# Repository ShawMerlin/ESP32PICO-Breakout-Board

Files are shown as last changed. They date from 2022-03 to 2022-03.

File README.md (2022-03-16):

# ESP32PICO-Breakout-Board

Here I have a simple breakout board for the new ESP32-PICO Chip.
All the parts I have included with JLCPCB Numbers so their assembly service can be used as well.

*Still getting some values on a few decoupling capacitors*

Pre-made Breakout boards for this are $30+ on sites so I wanted a cost effective option for testing this chip.
Feel free to take the Kicad files and change them however you see fit.  Enjoy!!

We want to update our ShawLED Controller board with this little chip, very exciting times!!
www.shawtechlighting.com

Features
* Full USB Integration
* A few breakout GPIO Pins (6)
* RX & TX USB Transfer LEDs
* Switch for hold in boot & reset
* 2 Antenna options (On Board and SMA)
* Switch for changing between the 2 Antenna's



3D Model of a Quarter was put in the picture to give an idea of how tiny this little guy is.  :)


I run a Facebook page for all my electronic/modding adventures.  I post things on there before they end up here on Github.
I love the feedback and comments that people share.  It helps us achieve bigger and better things!!

www.facebook.com/geekislandgaming

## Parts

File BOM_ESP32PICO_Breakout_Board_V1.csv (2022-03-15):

Comment | Designator | Footprint | LCSC | Type
SMA Board Edge Bend | AE2 | ANT-TH_KH-SMA-K513-G | C411575 | E
Boot Button - SKRKAEE020 | SW1,SW2 | SW-SMD-2_2.9x3.9x1.7 | C115357 | E
ANT_Sel | SW3 | SMD | C431540 | E
Diode | D1 | SOD-323 | C124187 | E
Power LED Blue | D2 | LED_0603 | C72041 | B
Orange LED | D3 | LED_0603
Green LED | D4 | LED_0603
10k | R1,R5 | 0603_Resistor | C25804 | B
0R | R2,R6 | 0603_Resistor | C21189 | B
47K | R3 | 0603_Resistor | C25819 | B
470R | R4 | 0603_Resistor | C23179 | B
1.2K Resistor | R7,R8,R9 | 0603_Resistor | C22765 | B
BCM857BS | Q1 | SOT65P210X110-6N | C105887 | E
UMH3N | Q2 | SMD:SOT-363 | C62892 | E
AO3401A | Q3 | SOT95P240X115-3N | C15127 | B
AMS1117 | U1 | SMD:SOT-223-3_TabPin2 | C6186 | B
CP2102 | U2 | QFN-28-1EP_5x5mm_P0.5mm_EP3.35x3.35mm | C6568 | B
TYPE-C-31-M-12 | USB1 | TYPE-C-31_L8.94_W7.3 | C165948 | E
 | C1
 | C3
 | C5
 | C6
.1uF | C2,C9 | 0603_Capacitor | C14663 | B
10uF | C4,C7,C8 | 0603_Capacitor | C96446 | B
ESP32-PICO-D4 | IC2 | QFN-48_EP_7.0x7.0x0.5P | C193707 | E
FerriteBead | FB1 | R_1206_3216Metric | C1002 | B

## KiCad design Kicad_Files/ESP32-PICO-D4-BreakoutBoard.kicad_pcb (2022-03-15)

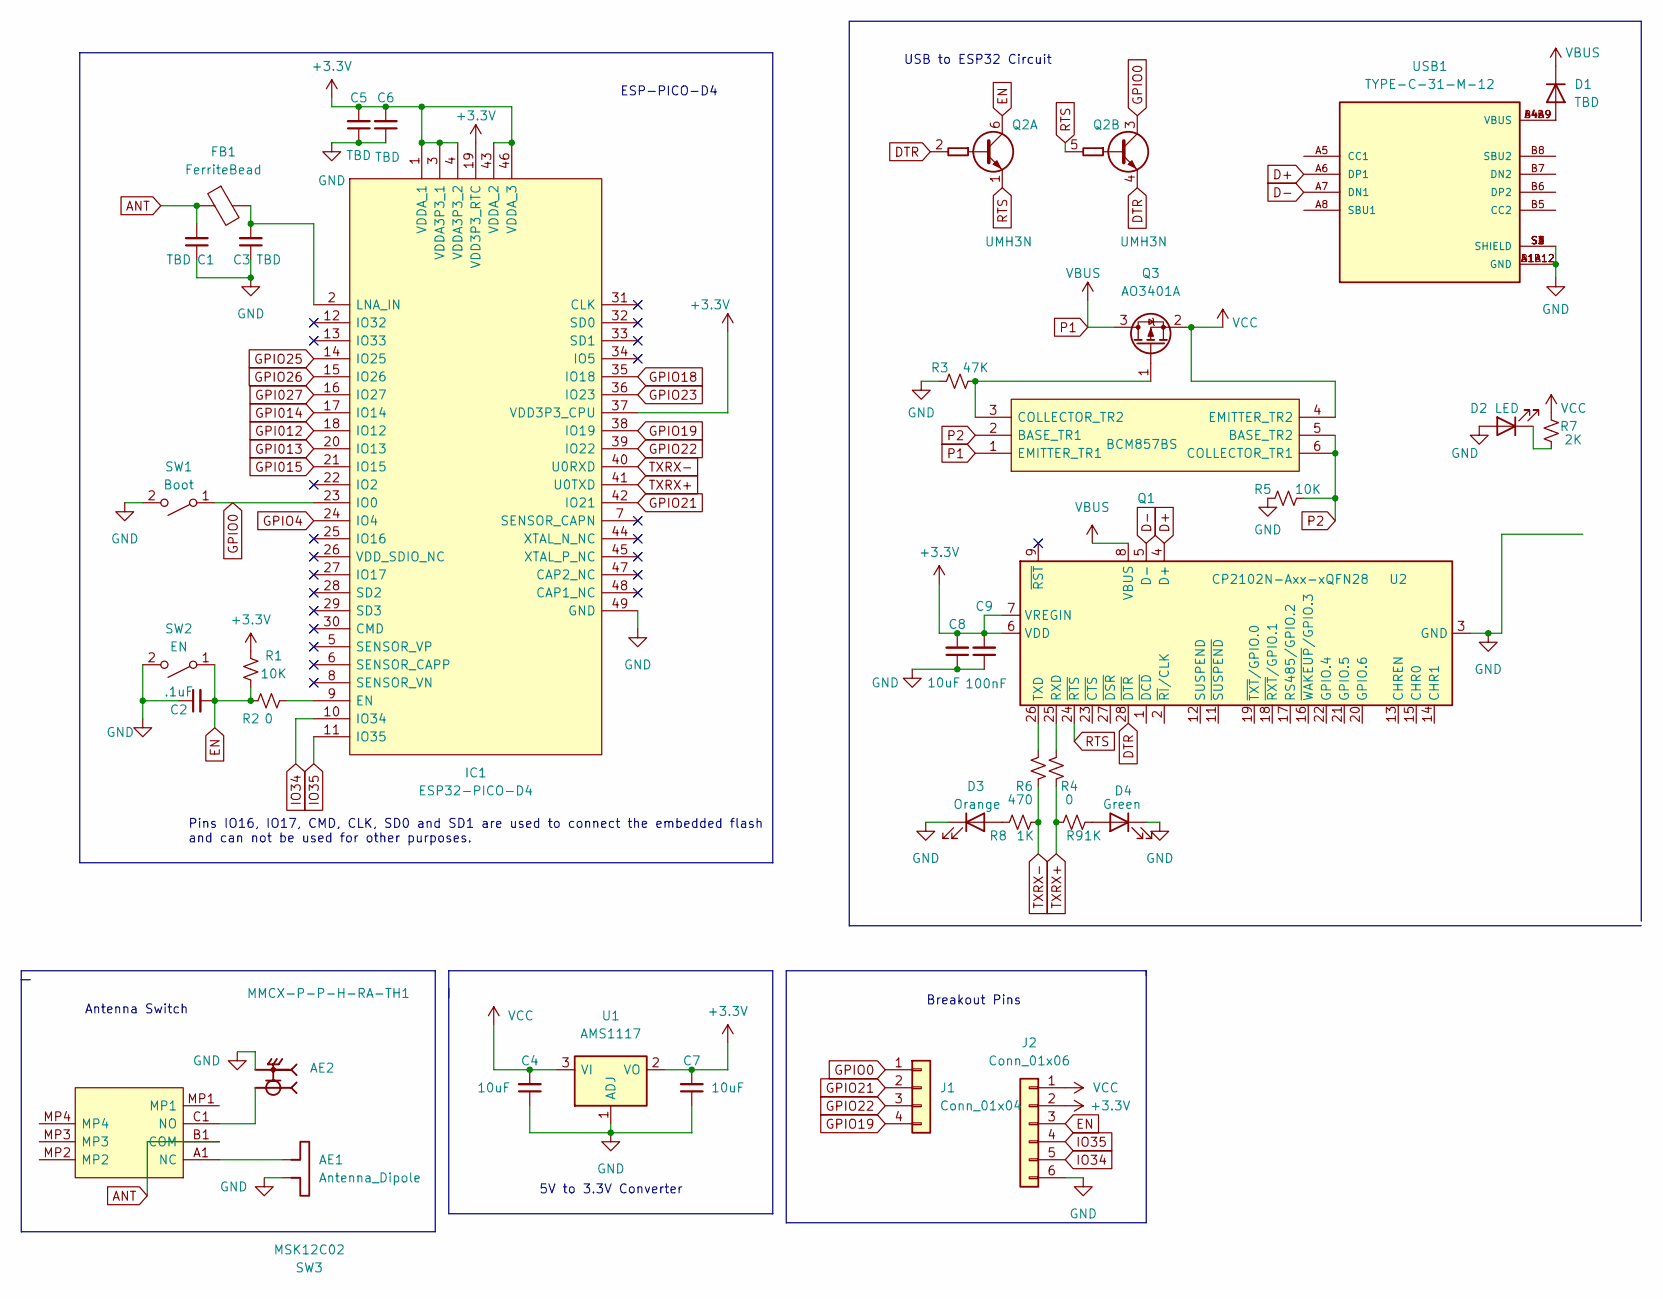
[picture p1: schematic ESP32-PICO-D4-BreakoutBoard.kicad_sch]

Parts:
AE1: Antenna_Dipole; Texas_SWRA117D_2.4GHz_Right
AE2: MMCX-P-P-H-RA-TH1; SAMTEC_MMCX-P-P-H-RA-TH1; PARTREV E
C1, C3, C5, C6: TBD; C_0603_1608Metric
C2: .1uF; C_0603_1608Metric
C4, C7, C8: 10uF; C_0603_1608Metric
C9: 100nF; C_0603_1608Metric
D1: TBD; DIODE_SOD2513X120N
D2: LED; LED_0603_1608Metric
D3: Orange; LED_0603_1608Metric
D4: Green; LED_0603_1608Metric
FB1: FerriteBead; R_1206_3216Metric
IC1: ESP32-PICO-D4; ESP32-PICO-D4-PQFN50P700X700X104-49N; Manufacturer_Part_Number ESP32-PICO-D4; Mouser Part Number 356-ESP32-PICO-D4
J1: Conn_01x04; PinSocket_1x04_P2.54mm_Vertical
J2: Conn_01x06; PinSocket_1x06_P2.54mm_Vertical
Q1: BCM857BS; BCM857BS_SOT65P210X110-6N; Manufacturer_Part_Number BCM857BS; Mouser Part Number N/A
Q2: UMH3N; SOT-363_SC-70-6
Q3: AO3401A; CJ2301_SOT95P240X115-3N
R1, R5: 10K; R_0603_1608Metric
R2, R6: 0; R_0603_1608Metric
R3: 47K; R_0603_1608Metric
R4: 470; R_0603_1608Metric
R7: 2K; R_0603_1608Metric
R8, R9: 1K; R_0603_1608Metric
SW1: Boot; Switch_SKRKAEE020
SW2: EN; Switch_SKRKAEE020
SW3: MSK12C02; Manufacturer_Part_Number MSK12C02
U1: AMS1117; SOT-223-3_TabPin2
U2: CP2102N-Axx-xQFN28; QFN-28-1EP_5x5mm_P0.5mm_EP3.35x3.35mm
USB1: TYPE-C-31-M-12; USBC_HRO_TYPE-C-31-M-12; PARTREV A

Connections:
+3V3: C5.2, C6.2, C7.2, C8.2, C9.2, IC1.1 (VDDA_1), IC1.3 (VDDA3P3_1), IC1.4 (VDDA3P3_2), IC1.19 (VDD3P3_RTC), IC1.37 (VDD3P3_CPU), IC1.43 (VDDA_2), IC1.46 (VDDA_3), J2.2, R1.2, U1.2 (VO), U2.6 (VDD), U2.7 (VREGIN)
ANT: C1.2, FB1.1, SW3.B1 (COM)
D+: U2.4 (D+), USB1.A6 (DP1)
D-: U2.5 (D-), USB1.A7 (DN1)
DTR: Q2.2 (B1), Q2.4 (E2), U2.28 (~DTR)
EN: C2.2, J2.3, Q2.6 (C1), R1.1, R2.1, SW2.1 (A)
GND: AE1.2, AE2.S1, AE2.S2, AE2.S3, AE2.S4, C1.1, C2.1, C3.1, C4.1, C5.1, C6.1, C7.1, C8.1, C9.1, D2.2 (A), D3.1 (K), D4.1 (K), IC1.49 (GND), J2.6, R3.1, R5.2, SW1.2 (B), SW2.2 (B), U1.1 (ADJ), U2.3 (GND), U2.29 (GND), USB1.A1B12 (GND), USB1.B1A12 (GND), USB1.S1 (SHIELD), USB1.S2 (SHIELD), USB1.S3 (SHIELD), USB1.S4 (SHIELD)
GPI012: IC1.18 (IO12)
GPI013: IC1.20 (IO13)
GPI014: IC1.17 (IO14)
GPI015: IC1.21 (IO15)
GPI027: IC1.16 (IO27)
GPIO0: IC1.23 (IO0), J1.1, Q2.3 (C2), SW1.1 (A)
GPIO4: IC1.24 (IO4)
GPIO18: IC1.35 (IO18)
GPIO19: IC1.38 (IO19), J1.4
GPIO21: IC1.42 (IO21), J1.2
GPIO22: IC1.39 (IO22), J1.3
GPIO23: IC1.36 (IO23)
GPIO25: IC1.14 (IO25)
GPIO26: IC1.15 (IO26)
IO34: IC1.10 (IO34), J2.5
IO35: IC1.11 (IO35), J2.4
unnamed: AE1.1, SW3.A1 (NC)
unnamed: C3.2, FB1.2, IC1.2 (LNA_IN)
unnamed: D1.2 (A), USB1.A4B9 (VBUS), USB1.B4A9 (VBUS)
unnamed: D2.1 (K), R7.2
unnamed: D3.2 (A), R8.1
unnamed: D4.2 (A), R9.2
unnamed: IC1.9 (EN), R2.2
unnamed: Q1.3 (COLLECTOR_TR2), Q3.1 (G), R3.2
unnamed: AE2.1, SW3.C1 (NO)
unnamed: R6.2, U2.25 (RXD)
unnamed: R4.2, U2.26 (TXD)
P1: D1.1 (K), Q1.1 (EMITTER_TR1), Q3.3 (D), U2.8 (VBUS)
P2: Q1.2 (BASE_TR1), Q1.5 (BASE_TR2), Q1.6 (COLLECTOR_TR1), R5.1
RTS: Q2.1 (E1), Q2.5 (B2), U2.24 (~RTS)
TXRX+: IC1.41 (U0TXD), R6.1, R9.1
TXRX-: IC1.40 (U0RXD), R4.1, R8.2
VCC: C4.2, J2.1, Q1.4 (EMITTER_TR2), Q3.2 (S), R7.1, U1.3 (VI)

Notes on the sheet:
Breakout Pins
USB to ESP32 Circuit
ESP-PICO-D4
Pins IO16, IO17, CMD, CLK, SD0 and SD1 are used to connect the embedded flash and can not be used for other purposes.
5V to 3.3V Converter
Antenna Switch

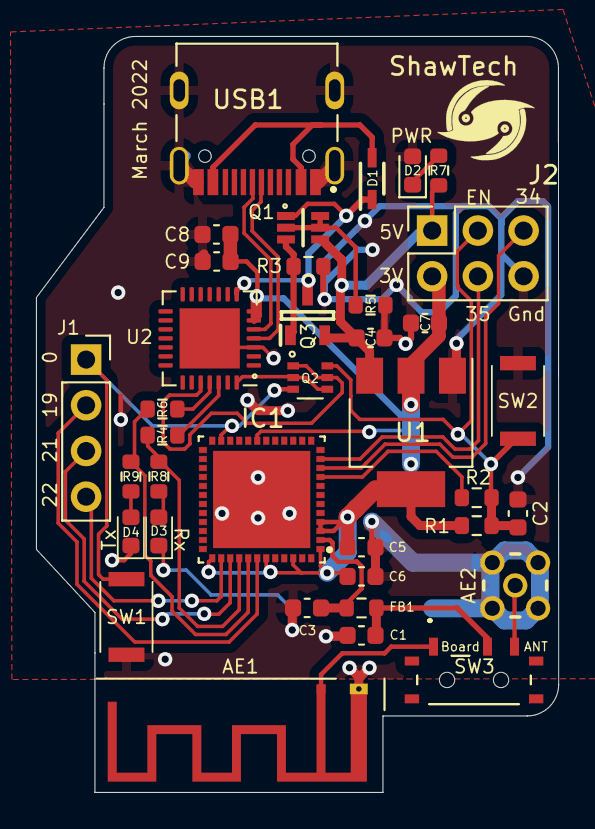
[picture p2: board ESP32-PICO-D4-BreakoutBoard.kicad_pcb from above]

Board: 2 copper layers, 29.0 x 42.0 mm, 37 parts (0 on the bottom side), 30 nets.
